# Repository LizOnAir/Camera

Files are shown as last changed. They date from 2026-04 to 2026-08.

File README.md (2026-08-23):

# Camera

This camera consist of a custom PCB and buttons as well as a 2.4 inch tft display with sd card slot, that can capture picture. I made this project to improve my knowledge about PCB design and also I personally really wanna make a retro camera with noisy resolution. Through this project, I learnt about high speed signals, parallel signals and heat management.

Screenshot 2026-04-14 at 4 07 00 PM

## Features:
- auto-focus 
- power with battery
- capture photos
- view photos

## CAD Model:
Screenshot 2026-04-10 at 10 55 10 AM
Screenshot 2026-04-10 at 10 56 41 AM
Screenshot 2026-04-10 at 10 56 52 AM

Made in Fusion360.Liz
Access files in [CAD folder](https://github.com/LizOnAir/Camera/tree/main/CAD).

## Assembly
Steps:
1.  Insert 4 heatset onto the 4 mounting holes in the bottom case.
2.  Insert the PCB into the bottom case.
3.  Using hot glue, stick the buttons onto the tactile switches.
4.  Align the holes of PCB onto the holes of the bottom case.
5.  Cover the top case over the bottom case.
6.  Screw them tight together.
7.  Charge the battery and use!!

## PCB
Here's my PCB! It was made in KiCad. 
### Schematic
Main board



Camera - OV5640



### PCB


Access files in [PCB folder](https://github.com/LizOnAir/Camera/tree/main/PCB).

## Firmware
I use Arduino IDE to program this camera
- dual state
    - capture image
    - review image

Access files in [Firmware folder](https://github.com/LizOnAir/Camera/tree/main/Firmware).

## BOM:
Here should be [everything](https://docs.google.com/spreadsheets/d/14nMMweMc_XzQDbo61nnmqZUTtTscH9UbB8BGQstIzH4/edit?usp=sharing) you need to make this:
- 1x PCBA
- 1x Ov5640
- 1x 3.7V Lipo Battery 500mAh
- 3x Tactile buttons
- 1x Slide switch
- 1x PH connector
- 1x Micro SD card
- 2.4 inch tft display
- 4x M3 14mm Screws
- 4x M3 OD4.2 L 4 Heatset inserts
- 1x 3d printed case

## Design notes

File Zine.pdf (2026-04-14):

# ESP32 CAMERA

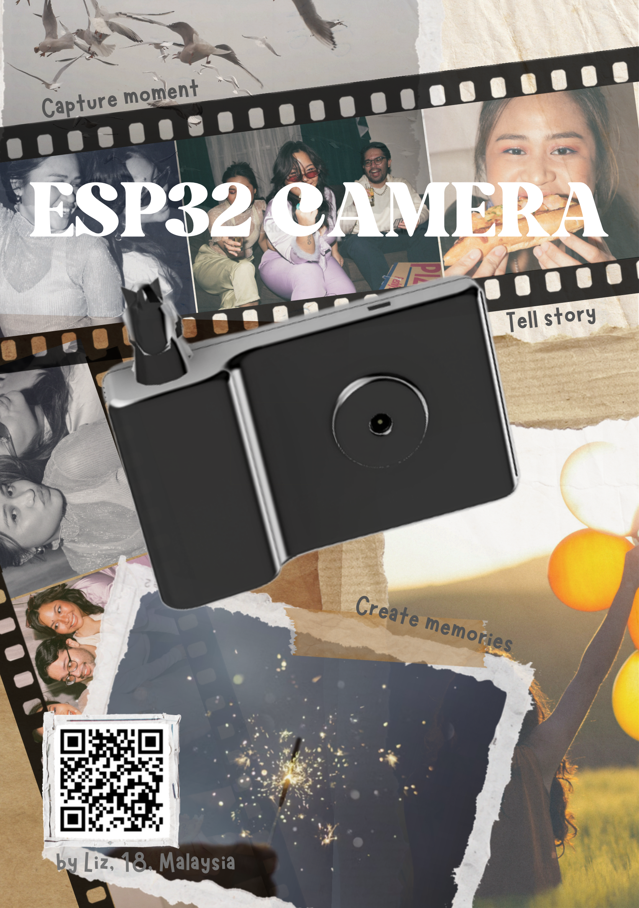
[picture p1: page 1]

Capture moment

Tell story

Create memories

byLiz,18, Malaysia

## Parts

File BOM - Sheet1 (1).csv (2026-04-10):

Name | Quantity | Price | Source
PCBA | 1 | $75.89 | https://cart.jlcpcb.com/quote?spm=jlcpcb.Public.2006
Ov5640 | 1 | $10.24 | https://www.aliexpress.com/item/1005003006706291.html
3.7V Lipo Battery 500mAh | 1 | $5.75 | https://www.aliexpress.com/item/1005008218024646.html
Tactile buttons | 1 | $1.25 | https://www.aliexpress.com/item/1005006880995108.html
Slide switch | 1 | $0.52 | https://www.aliexpress.com/item/4000699324084.html
PH connector | 1 | $1.89 | https://www.aliexpress.com/item/1005007425641197.html
micro SD card | 1 | $12.00 | https://www.aliexpress.com/item/1005010070877459.html
2.4 inch tft display | 1 | $3.43 | https://www.aliexpress.com/item/1005006109679854.html
M3 14mm Screws | 1 | $1.26 | https://www.aliexpress.com/item/1005007264845313.html
M3 OD4.2 L 4 Heatset inserts | 1 | $1.05 | https://www.aliexpress.com/item/1005007659182107.html
Total |  | $113.28

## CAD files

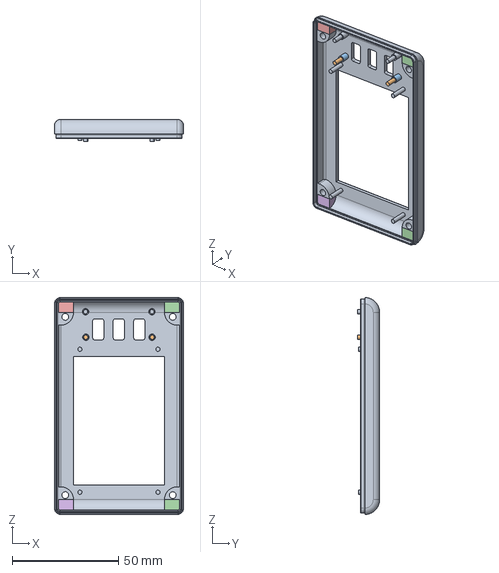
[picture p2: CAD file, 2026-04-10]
CAD/BackCase.step
60.8 x 10.5 x 102.1 mm

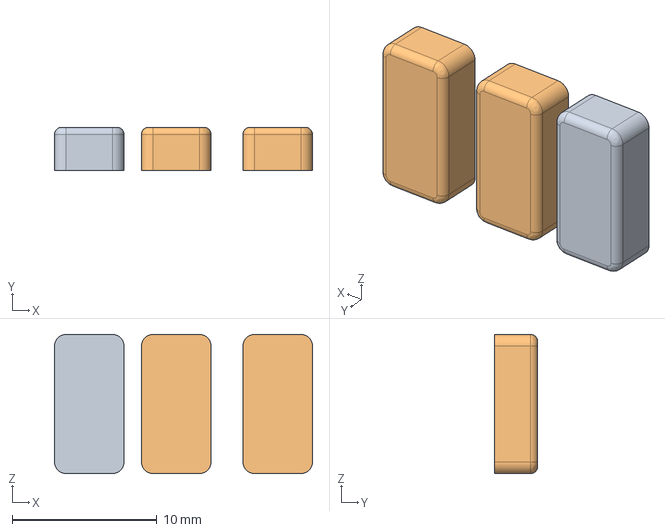
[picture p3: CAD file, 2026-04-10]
CAD/Buttons.step
17.8 x 3.00 x 9.60 mm

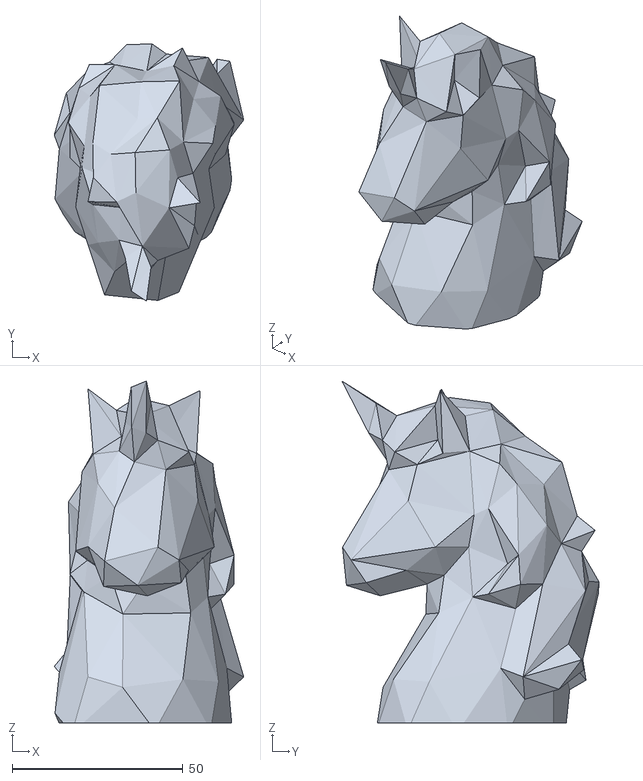
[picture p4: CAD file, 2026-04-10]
CAD/low_poly_unicorn.stl
55.4 x 75.2 x 100.0

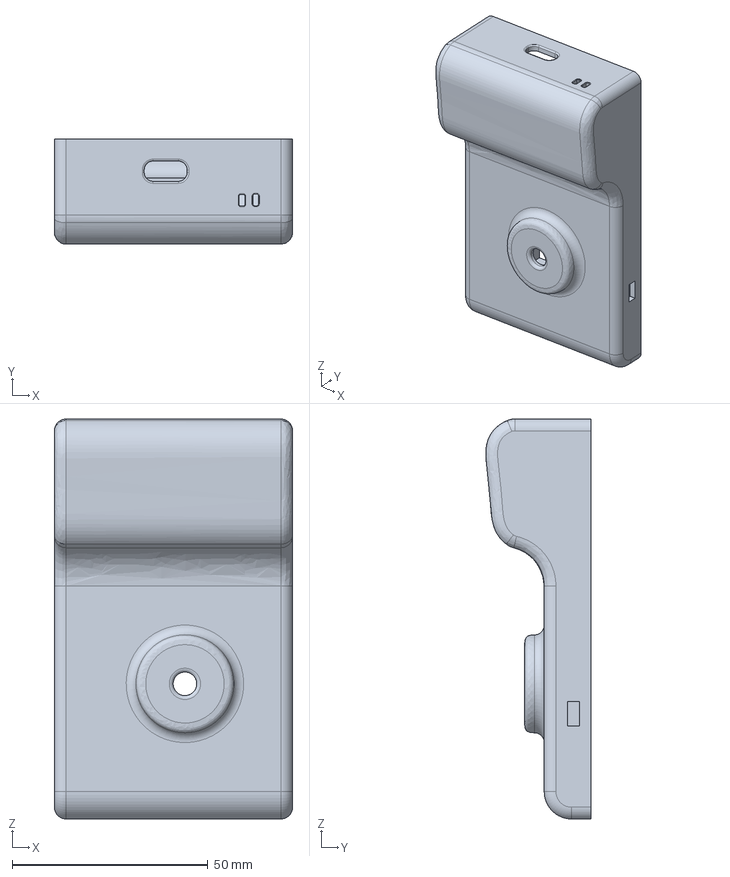
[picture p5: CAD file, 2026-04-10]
CAD/FrontCase.step
60.8 x 26.9 x 102.1 mm

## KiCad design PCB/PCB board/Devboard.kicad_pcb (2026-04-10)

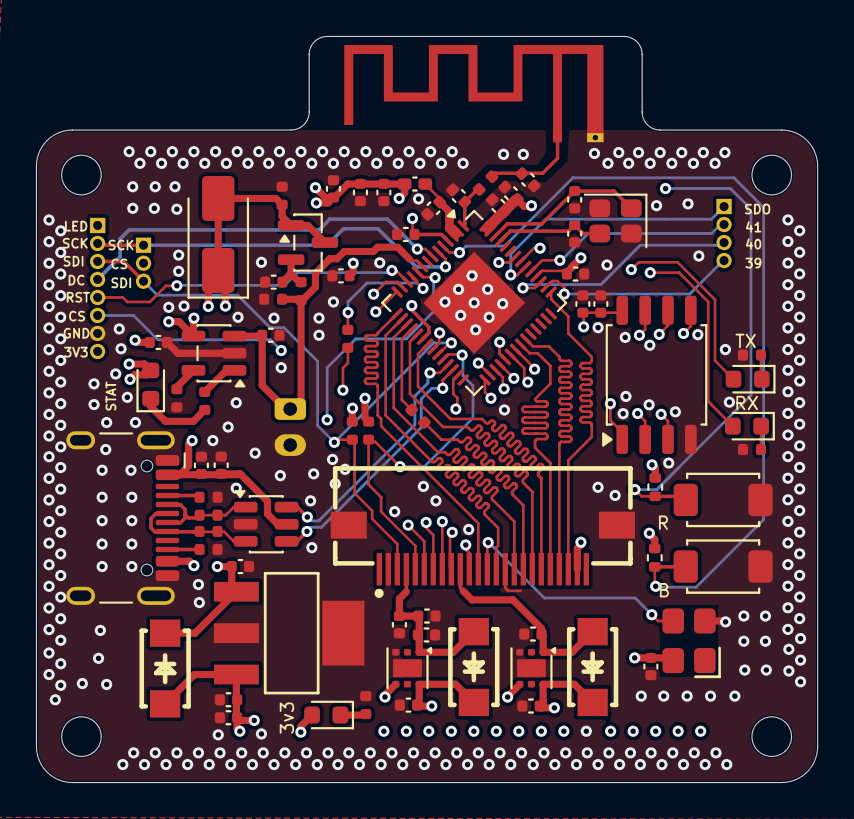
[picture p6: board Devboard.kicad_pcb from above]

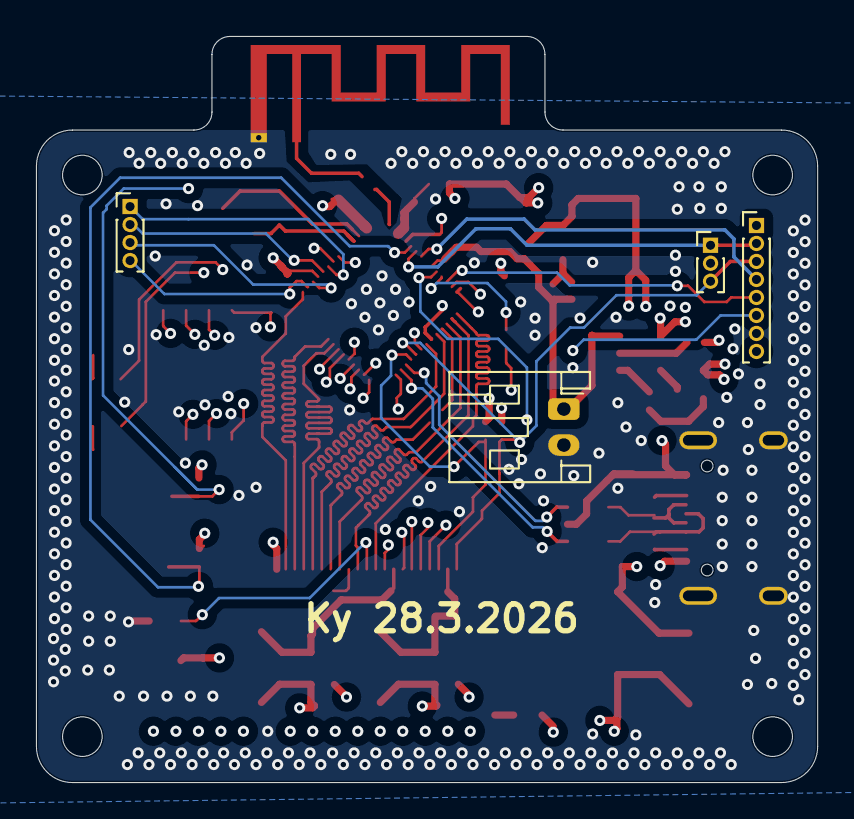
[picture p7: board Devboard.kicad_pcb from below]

Board: 4 copper layers, 43.4 x 41.5 mm, 77 parts (4 on the bottom side), 62 nets.

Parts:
AE1: Antenna_Chip; Texas_SWRA117D_2.4GHz_Left
C1, C2, C8, C12, C13, C14, C17, C20, C33, C34: 0.1uF; C_0402_1005Metric
C3, C7, C18, C21, C27, C28, C30: 1uF; C_0402_1005Metric
C4, C5, C10, C11, C26: 10UF; C_0402_1005Metric
C6, C19: 10nF; C_0402_1005Metric
C9, C15: 3pF; C_0402_1005Metric
C22, C23: 22pF; C_0402_1005Metric
C31, C32: 4.7UF; C_0402_1005Metric
CN1: FPC-SMD_KH-FG0.5-H2.0-24PIN
CN2: PH-2AK; JST_PH_S2B-PH-K_1x02_P2.00mm_Horizontal
D1, D3, D4, D6: LED; LED_0603_1608Metric
D2: SS14; D_SMA
D5, D7, D8: SS14
Flash1: Flash; SW_TS-1088-AR02016
J1: USB_C_Receptacle_USB2.0_14P; USB_C_Receptacle_HCTL_HC-TYPE-C-16P-01A
J3: Conn_01x08_Pin; PinHeader_1x08_P1.00mm_Vertical
J4: Conn_01x03_Pin; PinHeader_1x03_P1.00mm_Vertical
J5: Conn_01x04_Pin; PinHeader_1x04_P1.00mm_Vertical
L1: 2nH; L_0402_1005Metric_Pad0.77x0.64mm_HandSolder
L2: 2.4nH; L_0402
Q1: AO3401A; SOT-23
R1, R2: 5.1k; R_0402
R3, R10, R21, R22: 1k; R_0402
R4, R6: 10k; R_0402_1005Metric
R5, R11: 0; R_0402
R7, R8, R9: 470; R_0402
R14, R15: 33; R_0402
R18: 100k; R_0402
R19, R20: 200k; R_0402
Reset1: Reset; SW_TS-1088-AR02016
U1: c; QFN-56-1EP_7x7mm_P0.4mm_EP4x4mm
U3: MCP73831T-2DCI/OT; SOT-23-5
U4: W25Q128JVS; SOIC-8_5.3x5.3mm_P1.27mm
U5: TLV75515PDRV; WSON-6-1EP_2x2mm_P0.65mm_EP1x1.6mm
U6: TLV75518PDRV; WSON-6-1EP_2x2mm_P0.65mm_EP1x1.6mm
U7: USBLC6-2SC6; SOT-23-6
U8: AP2114HA-3_3TRG1
X2: 3N24000G33YC; OSC-SMD_4P-L3.2-W2.5-BL
Y1: 40MHz(10ppm); Crystal_SMD_2520-4Pin_2.5x2.0mm

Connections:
DAT0: CN1.19 (Y2), U1.21 (XTAL_32K_P)
DAT1: CN1.21 (Y3), U1.37 (SPICLK_P)
DAT2: CN1.22 (Y4/MDN0), U1.43 (GPIO38)
DAT3: CN1.20 (Y5/MDP0), U1.36 (SPICLK_N)
DAT4: CN1.18 (Y6/MCN), U1.19 (GPIO14)
DAT5: CN1.16 (Y7/MCP), U1.17 (GPIO12)
DAT6: CN1.14 (Y8/MDN1), U1.16 (GPIO11)
DAT7: CN1.12 (Y9/MDP1), U1.15 (GPIO10)
GND: AE1.2 (PCB_Trace), C1.2, C2.2, C3.2, C4.2, C5.2, C6.2, C7.2, C8.2, C9.2, C10.2, C11.2, C12.2, C13.2, C14.2, C15.2, C17.2, C18.2, C19.2, C20.2, C21.2, C22.2, C23.2, C26.2, C27.2, C28.2, C30.2, C31.2, C32.2, C33.2, C34.2, CN1.2 (AGND), CN1.15 (DGND), CN1.25 (GND), CN1.26 (GND), CN2.2, Flash1.1, J1.A1 (GND), J1.A12 (GND), J1.B1 (GND), J1.B12 (GND), J1.S1 (SHIELD), J3.7, R1.2, R2.2, R3.2, R7.1, R8.1, R9.1, R18.1, R20.2, Reset1.2, U1.57 (GND), U3.2 (V_{SS}), U4.4 (GND), U5.3 (GND), U5.7 (GND), U6.3 (GND), U6.7 (GND), U7.2 (GND), U8.2 (GND), U8.4 (GND), X2.2 (GND), Y1.2 (G), Y1.4 (G)
IO0: Flash1.2, R6.1, U1.5 (GPIO0)
IO1: J3.2, J4.1, U1.6 (GPIO1)
IO2: J3.4, U1.7 (GPIO2)
IO4/BAT: C11.1, CN2.1, R19.2, R20.1, U1.9 (GPIO4), U3.3 (V_{BAT})
IO7: J3.5, U1.12 (GPIO7)
IO13/PCLK: R11.1, U1.18 (GPIO13)
IO21: J3.6, U1.27 (GPIO21)
IO38/VSYNC: R5.1, U1.11 (GPIO6)
IO39: J5.4, U1.44 (MTCK)
IO40: J5.3, U1.45 (MTDO)
IO41: J5.2, U1.47 (MTDI)
IO42: J5.1, U1.48 (MTMS)
IO47/HREF: CN1.9 (HREF), U1.13 (GPIO8)
unnamed: AE1.1 (FEED), C9.1, L2.2
unnamed: C1.1, L1.2, U1.2 (VDD3P3), U1.3 (VDD3P3)
unnamed: CN1.17 (PCLK), R11.2
unnamed: CN1.7 (VSYNC), R5.2
unnamed: D1.1 (K), R10.2
unnamed: D3.1 (K), R7.2
unnamed: D4.1 (K), R8.2
unnamed: D6.1 (K), R9.2
unnamed: J1.A5 (CC1), R1.1
unnamed: J1.B5 (CC2), R2.1
unnamed: J1.A6 (D+), J1.B6 (D+), R15.1, R15.2, U7.3 (I/O2)
unnamed: J1.A7 (D-), J1.B7 (D-), R14.1, R14.2, U7.1 (I/O1)
unnamed: C26.1, Q1.2 (S), R19.1
unnamed: C14.1, R4.2, Reset1.1, U1.4 (CHIP_PU)
unnamed: C15.1, L2.1, U1.1 (LNA_IN)
unnamed: C22.1, U1.53 (XTAL_N), Y1.3
unnamed: C23.1, U1.54 (XTAL_P), Y1.1
unnamed: R3.1, U3.5 (PROG)
unnamed: R10.1, U3.1 (STAT)
PWDN: CN1.8 (PWDN), U1.14 (GPIO9)
RESET: CN1.6 (RESET), U1.10 (GPIO5)
RX: D6.2 (A), U1.50 (U0RXD)
SCL: CN1.5 (SIO-C), R22.2, U1.24 (GPIO18)
SDA: CN1.3 (SIO-D), J3.3, J4.3, R21.2, U1.23 (GPIO17)
SPICLK: U1.33 (SPICLK), U4.6 (CLK)
SPICS0: U1.32 (SPICS0), U4.1 (~CS)
SPID: U1.35 (SPID), U4.5 (DI/IO_{0})
SPIHD: U1.30 (SPIHD), U4.7 (~HOLD/~RESET/IO_{3})
SPIQ: U1.34 (SPIQ), U4.2 (DO/IO_{1})
SPIWP: U1.31 (SPIWP), U4.3 (~WP/IO_{2})
TX: D4.2 (A), U1.49 (U0TXD)
USB_D+: U1.26 (GPIO20/USB_D+), U7.4 (I/O2)
USB_D-: U1.25 (GPIO19/USB_D-), U7.6 (I/O1)
VDDIO: C2.1, C3.1, C4.1, C6.1, C7.1, C12.1, C13.1, C17.1, C18.1, C19.1, C27.1, C31.1, CN1.11 (DOVDD), CN1.23 (AF-VDD), D3.2 (A), D5.2 (A), D7.1 (K), D8.1 (K), J3.1, J3.8, L1.1, R4.1, R6.2, R21.1, R22.1, U1.20 (VDD3P3_RTC), U1.46 (VDD3P3_CPU), U1.55 (VDDA), U1.56 (VDDA), U5.4 (EN), U5.6 (IN), U6.4 (EN), U6.6 (IN), U8.3 (OUT), X2.4 (VDD)
VDD_1.5V: C28.1, CN1.10 (DVDD), D7.2 (A), U5.1 (OUT)
VDD_2.8V: C30.1, C33.1, C34.1, CN1.4 (AVDD), D8.2 (A), U6.1 (OUT)
VDD_SPI: C20.1, C21.1, U1.29 (VDD_SPI), U4.8 (VCC)
VSYS: C5.1, C8.1, C10.1, C32.1, D1.2 (A), D2.1 (K), D2.2 (A), D5.1 (K), J1.A4 (VBUS), J1.A9 (VBUS), J1.B4 (VBUS), J1.B9 (VBUS), Q1.1 (G), Q1.3 (D), R18.2, U3.4 (V_{DD}), U7.5 (VBUS), U8.1 (IN)
XCLK: CN1.13 (XCLK), X2.3 (OUT)
XTAL_32P: J4.2, U1.22 (XTAL_32K_N)

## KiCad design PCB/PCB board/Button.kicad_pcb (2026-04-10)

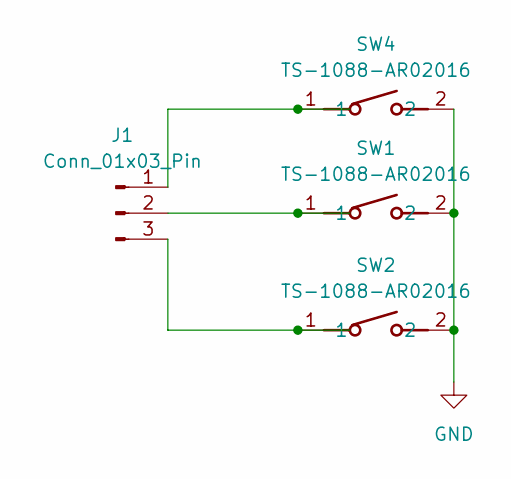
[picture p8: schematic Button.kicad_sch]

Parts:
J1: Conn_01x03_Pin; PinHeader_1x03_P1.00mm_Vertical
SW1, SW2, SW4: TS-1088-AR02016; C13828; Manufacturer Part TS-1088-AR02016; LCSC C720477

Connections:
GND: SW1.2, SW2.2, SW4.2
unnamed: J1.1, SW4.1
unnamed: J1.2, SW1.1
unnamed: J1.3, SW2.1

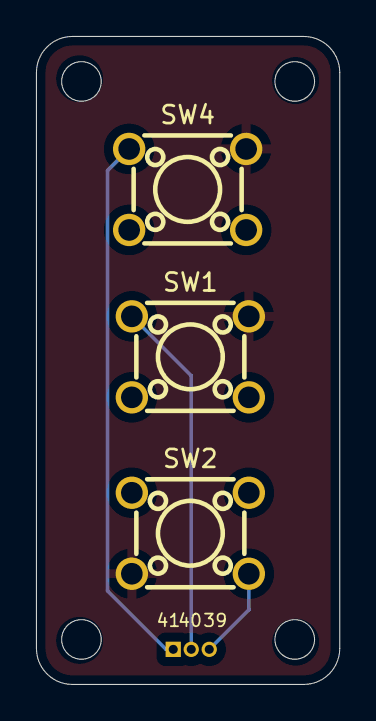
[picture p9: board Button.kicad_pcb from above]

Board: 2 copper layers, 16.8 x 36.0 mm, 4 parts (1 on the bottom side), 4 nets.

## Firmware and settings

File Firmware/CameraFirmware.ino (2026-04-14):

/*
 * ESP32-S3 Camera + TFT ST7735 + SD Card Firmware
 * OV5640 Camera, 2.4" ST7735 TFT Display
 *
 * ─── 引脚分配 ────────────────────────────────────────────────────────────────
 *  Camera (DVP 并行):
 *    PWDN=9  RESET=5  XCLK=内部  SIOD=17  SIOC=18
 *    Y2-Y9 = 16,47,30,48,14,12,11,10
 *    VSYNC=6  HREF=8  PCLK=13
 *
 *  TFT ST7735 (SPI):
 *    MOSI=2   SCLK=1   CS=21   DC=7   RST=3
 *    ※ MOSI 已从 GPIO17 改为 GPIO2，与摄像头 SCCB 完全隔离，无冲突
 *
 *  SD Card (SD_MMC 1-bit):
 *    由 SD_MMC 库管理，1-bit 模式
 *
 *  Buttons:
 *    MenuBTN=41  BTN1=40  BTN2=39
 *
 * ─── 状态机 ──────────────────────────────────────────────────────────────────
 *   STATE_CAMERA  → 实时预览，BTN1=拍照保存
 *   STATE_REVIEW  → SD卡照片浏览，BTN1=上一张，BTN2=下一张
 *   MenuBTN 切换: STATE_CAMERA ↔ STATE_REVIEW
 * ────────────────────────────────────────────────────────────────────────────
 */

#include "esp_camera.h"
#include "Arduino.h"
#include "soc/soc.h"
#include "soc/rtc_cntl_reg.h"
#include "driver/rtc_io.h"
#include <EEPROM.h>
#include <SPI.h>
#include <TFT_eSPI.h>
#include "FS.h"
#include "SD_MMC.h"
#include "esp_jpg_decode.h"

// ─── Camera Pin Definitions ───────────────────────────────────────────────────
#define PWDN_GPIO_NUM     9
#define RESET_GPIO_NUM    5
#define XCLK_GPIO_NUM    -1   // Use internal clock
#define SIOD_GPIO_NUM    17
#define SIOC_GPIO_NUM    18
#define Y9_GPIO_NUM      10
#define Y8_GPIO_NUM      11
#define Y7_GPIO_NUM      12
#define Y6_GPIO_NUM      14
#define Y5_GPIO_NUM      48
#define Y4_GPIO_NUM      30
#define Y3_GPIO_NUM      47
#define Y2_GPIO_NUM      16
#define VSYNC_GPIO_NUM    6
#define HREF_GPIO_NUM     8
#define PCLK_GPIO_NUM    13

// ─── TFT Pin Definitions ──────────────────────────────────────────────────────
// 在 TFT_eSPI 的 User_Setup.h 中配置以下引脚：
//   #define TFT_MOSI  2    // ← 已从 17 改为 2（与摄像头 SCCB 完全隔离）
//   #define TFT_SCLK  1
//   #define TFT_CS   21
//   #define TFT_DC    7    // ← 已从 2 改为 7
//   #define TFT_RST   3    // ← 已从 7 改为 3
// （或在 platformio.ini / build_flags 中用 -D 宏覆盖）
#define TFT_MOSI_PIN  2
#define TFT_SCLK_PIN  1
#define TFT_CS_PIN   21
#define TFT_DC_PIN    7
#define TFT_RST_PIN   3

// ─── Button Definitions ───────────────────────────────────────────────────────
#define menuBTN  41
#define BTN1     40
#define BTN2     39

// ─── Display resolution ───────────────────────────────────────────────────────
#define TFT_W    240
#define TFT_H    320

// ─── EEPROM ───────────────────────────────────────────────────────────────────
#define EEPROM_SIZE 4  // Store int (picture count)

// ─── State Machine ────────────────────────────────────────────────────────────
typedef enum {
  STATE_CAMERA = 0,   // 实时摄像头预览
  STATE_REVIEW  = 1   // SD卡照片浏览
} AppState;

// ─── Globals ─────────────────────────────────────────────────────────────────
TFT_eSPI tft = TFT_eSPI();

AppState currentState = STATE_CAMERA;

int totalPictures  = 0;   // 已保存照片总数（从 EEPROM 读取）
int viewIndex      = 0;   // 当前浏览的照片序号（0-based）

// 按键防抖
unsigned long lastMenuTime = 0;
unsigned long lastBtn1Time = 0;
unsigned long lastBtn2Time = 0;
#define DEBOUNCE_MS 250

// JPEG 解码缓冲区（RGB565 格式）
uint16_t *jpegBuf = nullptr;

// ─── Forward Declarations ────────────────────────────────────────────────────
bool initCamera();
bool initDisplay();
bool initSDCard();
void showCameraFrame();
void captureAndSave();
void showImageFromSD(int index);
void drawStatusBar(const char* msg);
bool readButtons(bool &menuPressed, bool &btn1Pressed, bool &btn2Pressed);

// ─── JPEG decode callback (rgb565 line-by-line to TFT) ───────────────────────
// We use a simple approach: decode JPEG → push to TFT via esp_jpg_decode
// The decoded pixel callback writes directly to the TFT

struct JpegDecode {
  int x_offset;
  int y_offset;
  uint16_t *linebuf;
  int linebuf_width;
};

static bool jpg_write_cb(void *arg, uint16_t x, uint16_t y,
                         uint16_t w, uint16_t h, uint8_t *data) {
  if (!data) return true;
  JpegDecode *ctx = (JpegDecode *)arg;
  // data is RGB888, convert to RGB565 and push
  tft.startWrite();
  tft.setAddrWindow(ctx->x_offset + x, ctx->y_offset + y, w, h);
  for (uint32_t i = 0; i < (uint32_t)(w * h); i++) {
    uint8_t r = data[i * 3 + 0];
    uint8_t g = data[i * 3 + 1];
    uint8_t b = data[i * 3 + 2];
    uint16_t rgb565 = ((r & 0xF8) << 8) | ((g & 0xFC) << 3) | (b >> 3);
    tft.pushColor(rgb565);
  }
  tft.endWrite();
  return true;
}

// ─── Setup ────────────────────────────────────────────────────────────────────
void setup() {
  WRITE_PERI_REG(RTC_CNTL_BROWN_OUT_REG, 0); // 禁用欠压检测

  Serial.begin(115200);
  Serial.setDebugOutput(true);
  Serial.println("[BOOT] ESP32-S3 Camera Starting...");

  // 按键初始化
  pinMode(menuBTN, INPUT_PULLUP);
  pinMode(BTN1,    INPUT_PULLUP);
  pinMode(BTN2,    INPUT_PULLUP);

  // EEPROM 初始化，读取已保存照片数量
  EEPROM.begin(EEPROM_SIZE);
  EEPROM.get(0, totalPictures);
  if (totalPictures < 0 || totalPictures > 9999) totalPictures = 0;
  Serial.printf("[EEPROM] Total pictures stored: %d\n", totalPictures);

  // ── Step 1: 显示器初始化（GPIO2=MOSI 与摄像头无冲突，先启动）────────────
  if (!initDisplay()) {
    Serial.println("[ERROR] Display init failed!");
    // 不 halt，继续运行
  }

  // ── Step 2: 摄像头初始化（GPIO17=SCCB SDA，与 TFT 引脚完全隔离）─────────
  if (!initCamera()) {
    tft.fillScreen(TFT_RED);
    tft.setTextColor(TFT_WHITE, TFT_RED);
    tft.setTextSize(2);
    tft.setCursor(10, TFT_H / 2 - 10);
    tft.print("Camera FAILED");
    Serial.println("[ERROR] Camera init failed! Halting.");
    while (1) delay(1000);
  }
  tft.fillScreen(TFT_BLACK);
  tft.setTextColor(TFT_GREEN, TFT_BLACK);
  tft.setTextSize(2);
  tft.setCursor(20, TFT_H / 2 - 10);
  tft.print("Camera OK");
  delay(400);

  // SD 卡初始化
  if (!initSDCard()) {
    drawStatusBar("SD Card FAILED");
    Serial.println("[WARN] SD Card init failed — saving disabled");
  }

  Serial.println("[BOOT] Ready.");
}

// ─── Loop ─────────────────────────────────────────────────────────────────────
void loop() {
  bool menuPressed = false, btn1Pressed = false, btn2Pressed = false;
  readButtons(menuPressed, btn1Pressed, btn2Pressed);

  switch (currentState) {

    // ── 实时预览模式 ──────────────────────────────────────────────────────────
    case STATE_CAMERA:
      showCameraFrame();

      if (menuPressed) {
        // 切换到浏览模式，显示最新照片
        Serial.println("[STATE] → REVIEW");
        currentState = STATE_REVIEW;
        viewIndex = (totalPictures > 0) ? (totalPictures - 1) : 0;
        if (totalPictures > 0) {
          showImageFromSD(viewIndex);
        } else {
          tft.fillScreen(TFT_BLACK);
          tft.setTextColor(TFT_WHITE);
          tft.setTextSize(2);
          tft.setCursor(20, TFT_H / 2);
          tft.print("No photos yet");
          drawStatusBar("MenuBTN: back");
        }
      }

      if (btn1Pressed) {
        // BTN1 → 拍照保存
        captureAndSave();
      }
      break;

    // ── 照片浏览模式 ──────────────────────────────────────────────────────────
    case STATE_REVIEW:
      if (menuPressed) {
        // 再按 MenuBTN → 回到摄像头预览
        Serial.println("[STATE] → CAMERA");
        currentState = STATE_CAMERA;
        tft.fillScreen(TFT_BLACK);
      }

      if (btn1Pressed && totalPictures > 0) {
        // BTN1 → 上一张
        viewIndex--;
        if (viewIndex < 0) viewIndex = totalPictures - 1;
        Serial.printf("[REVIEW] Showing image %d\n", viewIndex);
        showImageFromSD(viewIndex);
      }

      if (btn2Pressed && totalPictures > 0) {
        // BTN2 → 下一张
        viewIndex++;
        if (viewIndex >= totalPictures) viewIndex = 0;
        Serial.printf("[REVIEW] Showing image %d\n", viewIndex);
        showImageFromSD(viewIndex);
      }
      break;
  }
}

// ─── Camera Init ─────────────────────────────────────────────────────────────
bool initCamera() {
  camera_config_t config;
  config.ledc_channel = LEDC_CHANNEL_0;
  config.ledc_timer   = LEDC_TIMER_0;
  config.pin_d0       = Y2_GPIO_NUM;
  config.pin_d1       = Y3_GPIO_NUM;
  config.pin_d2       = Y4_GPIO_NUM;
  config.pin_d3       = Y5_GPIO_NUM;
  config.pin_d4       = Y6_GPIO_NUM;
  config.pin_d5       = Y7_GPIO_NUM;
  config.pin_d6       = Y8_GPIO_NUM;
  config.pin_d7       = Y9_GPIO_NUM;
  config.pin_xclk     = XCLK_GPIO_NUM;
  config.pin_pclk     = PCLK_GPIO_NUM;
  config.pin_vsync    = VSYNC_GPIO_NUM;
  config.pin_href     = HREF_GPIO_NUM;
  config.pin_sccb_sda = SIOD_GPIO_NUM;
  config.pin_sccb_scl = SIOC_GPIO_NUM;
  config.pin_pwdn     = PWDN_GPIO_NUM;
  config.pin_reset    = RESET_GPIO_NUM;
  config.xclk_freq_hz = 20000000;
  config.pixel_format = PIXFORMAT_JPEG;
  config.grab_mode    = CAMERA_GRAB_WHEN_EMPTY;

  if (psramFound()) {
    config.frame_size   = FRAMESIZE_QVGA;  // 320x240，适合TFT显示
    config.jpeg_quality = 12;
    config.fb_count     = 2;
    Serial.println("[CAM] PSRAM found — QVGA, 2 buffers");
  } else {
    config.frame_size   = FRAMESIZE_QVGA;
    config.jpeg_quality = 15;
    config.fb_count     = 1;
    Serial.println("[CAM] No PSRAM — QVGA, 1 buffer");
  }

  esp_err_t err = esp_camera_init(&config);
  if (err != ESP_OK) {
    Serial.printf("[CAM] Init failed: 0x%x\n", err);
    return false;
  }

  // OV5640 sensor settings
  sensor_t *s = esp_camera_sensor_get();
  if (s) {
    s->set_brightness(s, 0);
    s->set_saturation(s, 0);
    s->set_gainceiling(s, (gainceiling_t)6);
    s->set_whitebal(s, 1);
    s->set_awb_gain(s, 1);
    s->set_wb_mode(s, 0);
    s->set_exposure_ctrl(s, 1);
    s->set_aec2(s, 0);
    s->set_gain_ctrl(s, 1);
    s->set_agc_gain(s, 0);
    s->set_bpc(s, 0);
    s->set_wpc(s, 1);
    s->set_raw_gma(s, 1);
    s->set_lenc(s, 1);
    s->set_hmirror(s, 0);
    s->set_vflip(s, 0);
    Serial.println("[CAM] OV5640 sensor configured");
  }

  return true;
}

// ─── Display Init ────────────────────────────────────────────────────────────
bool initDisplay() {
  tft.init();
  tft.setRotation(0);          // Portrait
  tft.fillScreen(TFT_BLACK);
  tft.setTextColor(TFT_WHITE, TFT_BLACK);
  tft.setTextSize(2);
  tft.setCursor(20, TFT_H / 2 - 10);
  tft.print("Initializing...");
  Serial.println("[TFT] Display initialized");
  return true;
}

// ─── SD Card Init ────────────────────────────────────────────────────────────
bool initSDCard() {
  // SD_MMC uses built-in MMC interface (1-bit mode for fewer pins)
  if (!SD_MMC.begin("/sdcard", true)) {  // true = 1-bit mode
    Serial.println("[SD] Mount failed");
    return false;
  }
  uint8_t cardType = SD_MMC.cardType();
  if (cardType == CARD_NONE) {
    Serial.println("[SD] No card detected");
    return false;
  }
  Serial.printf("[SD] Card type: %d, Size: %llu MB\n",
                cardType, SD_MMC.cardSize() / (1024 * 1024));
  return true;
}

// ─── Show Camera Frame ───────────────────────────────────────────────────────
void showCameraFrame() {
  camera_fb_t *fb = esp_camera_fb_get();
  if (!fb) {
    Serial.println("[CAM] Capture failed");
    delay(100);
    return;
  }

  if (fb->format == PIXFORMAT_JPEG) {
    // JPEG → RGB565 → TFT
    JpegDecode ctx;
    ctx.x_offset = 0;
    ctx.y_offset = 0;
    // esp_jpg_decode 解码 JPEG 并回调写入 TFT
    esp_jpg_decode(fb->buf, fb->len, JPG_SCALE_NONE,
                   jpg_write_cb, (void *)&ctx);
  } else if (fb->format == PIXFORMAT_RGB565) {
    tft.startWrite();
    tft.setAddrWindow(0, 0, TFT_W, TFT_H);
    tft.pushPixels((uint16_t *)fb->buf, TFT_W * TFT_H);
    tft.endWrite();
  }

  esp_camera_fb_return(fb);
}

// ─── Capture & Save to SD ────────────────────────────────────────────────────
void captureAndSave() {
  // 拍摄一帧（提高画质）
  sensor_t *s = esp_camera_sensor_get();
  if (s) {
    s->set_framesize(s, FRAMESIZE_SVGA);  // 拍照用更高分辨率
    s->set_jpeg_quality(s, 8);
  }
  delay(200);  // 让曝光稳定

  camera_fb_t *fb = esp_camera_fb_get();
  if (!fb) {
    Serial.println("[CAM] Capture failed");
    drawStatusBar("Capture FAILED");
    delay(1000);
    return;
  }

  // 文件名: /pic_0001.jpg
  char path[32];
  snprintf(path, sizeof(path), "/pic_%04d.jpg", totalPictures);

  File f = SD_MMC.open(path, FILE_WRITE);
  if (!f) {
    Serial.printf("[SD] Failed to open %s for writing\n", path);
    drawStatusBar("SD Write FAILED");
  } else {
    f.write(fb->buf, fb->len);
    f.close();
    totalPictures++;
    EEPROM.put(0, totalPictures);
    EEPROM.commit();
    Serial.printf("[SD] Saved: %s (%zu bytes)\n", path, fb->len);

    // 显示保存成功提示
    char msg[40];
    snprintf(msg, sizeof(msg), "Saved: pic_%04d.jpg", totalPictures - 1);
    drawStatusBar(msg);
  }

  esp_camera_fb_return(fb);

  // 恢复预览分辨率
  if (s) {
    s->set_framesize(s, FRAMESIZE_QVGA);
    s->set_jpeg_quality(s, 12);
  }

  delay(1000);  // 显示保存提示1秒
}

// ─── Show Image from SD ──────────────────────────────────────────────────────
void showImageFromSD(int index) {
  if (totalPictures == 0) return;

  char path[32];
  snprintf(path, sizeof(path), "/pic_%04d.jpg", index);

  File f = SD_MMC.open(path, FILE_READ);
  if (!f) {
    Serial.printf("[SD] Failed to open %s\n", path);
    tft.fillScreen(TFT_BLACK);
    tft.setTextColor(TFT_RED);
    tft.setTextSize(2);
    tft.setCursor(10, TFT_H / 2);
    tft.printf("Cannot open\npic_%04d.jpg", index);
    return;
  }

  size_t fileSize = f.size();
  uint8_t *jpgData = (uint8_t *)malloc(fileSize);
  if (!jpgData) {
    Serial.println("[MEM] malloc failed for JPEG buffer");
    f.close();
    return;
  }

  f.read(jpgData, fileSize);
  f.close();

  tft.fillScreen(TFT_BLACK);

  JpegDecode ctx;
  ctx.x_offset = 0;
  ctx.y_offset = 0;
  esp_jpg_decode(jpgData, fileSize, JPG_SCALE_NONE, jpg_write_cb, (void *)&ctx);

  free(jpgData);

  // 显示状态栏
  char msg[40];
  snprintf(msg, sizeof(msg), "%d / %d  B1:Prev B2:Next", index + 1, totalPictures);
  drawStatusBar(msg);

  Serial.printf("[REVIEW] Displayed: %s\n", path);
}

// ─── Status Bar ──────────────────────────────────────────────────────────────
void drawStatusBar(const char *msg) {
  // 在屏幕底部显示状态信息
  tft.fillRect(0, TFT_H - 20, TFT_W, 20, TFT_NAVY);
  tft.setTextColor(TFT_WHITE, TFT_NAVY);
  tft.setTextSize(1);
  tft.setCursor(2, TFT_H - 14);
  tft.print(msg);
}

// ─── Button Reading with Debounce ────────────────────────────────────────────
bool readButtons(bool &menuPressed, bool &btn1Pressed, bool &btn2Pressed) {
  unsigned long now = millis();

  menuPressed = false;
  btn1Pressed = false;
  btn2Pressed = false;

  // LOW = 按下 (INPUT_PULLUP)
  if (digitalRead(menuBTN) == LOW && (now - lastMenuTime) > DEBOUNCE_MS) {
    menuPressed   = true;
    lastMenuTime  = now;
    Serial.println("[BTN] MENU pressed");
  }

  if (digitalRead(BTN1) == LOW && (now - lastBtn1Time) > DEBOUNCE_MS) {
    btn1Pressed  = true;
    lastBtn1Time = now;
    Serial.println("[BTN] BTN1 pressed");
  }

  if (digitalRead(BTN2) == LOW && (now - lastBtn2Time) > DEBOUNCE_MS) {
    btn2Pressed  = true;
    lastBtn2Time = now;
    Serial.println("[BTN] BTN2 pressed");
  }

  return menuPressed || btn1Pressed || btn2Pressed;
}

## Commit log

2026-04-10 Add README for camera project with features and PCB info
    Added detailed information about the camera, including features, CAD model, PCB schematics, and BOM link.
2026-04-10 Add Camera schematic file
    [Camera.kicad_sch]
2026-04-10 Rename PCB/Button.kicad_pcb to PCB/PCB board/Button.kicad_pcb
    [Button.kicad_pcb]
2026-04-10 Rename PCB/Devboard.kicad_pcb to PCB/PCB board/Devboard.kicad_pcb
    [Devboard.kicad_pcb]
2026-04-14 Enhance README with project insights and links
    Expanded project description with additional learning insights and added links to PCB and Firmware folders.
2026-08-23 Add assembly steps to README
    Added assembly instructions for the project.
